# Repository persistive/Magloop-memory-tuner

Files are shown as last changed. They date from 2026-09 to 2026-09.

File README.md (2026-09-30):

# Magloop-memory-tuner
Using a CYD to steer a servo for the magloop variable condensator.
A tuning device with memory option for operating a magloop air capacitor The sketch is available in dutch and english language, functionality is the same. Base is a CYD unit for which a suitable casing is developed. Connections are part of the description in the .ino files

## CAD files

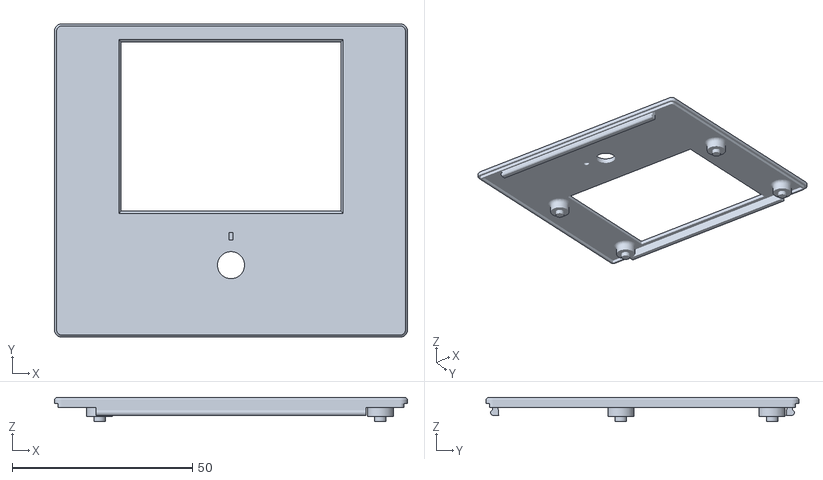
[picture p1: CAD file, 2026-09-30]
case front.stl
98.0 x 87.0 x 6.80

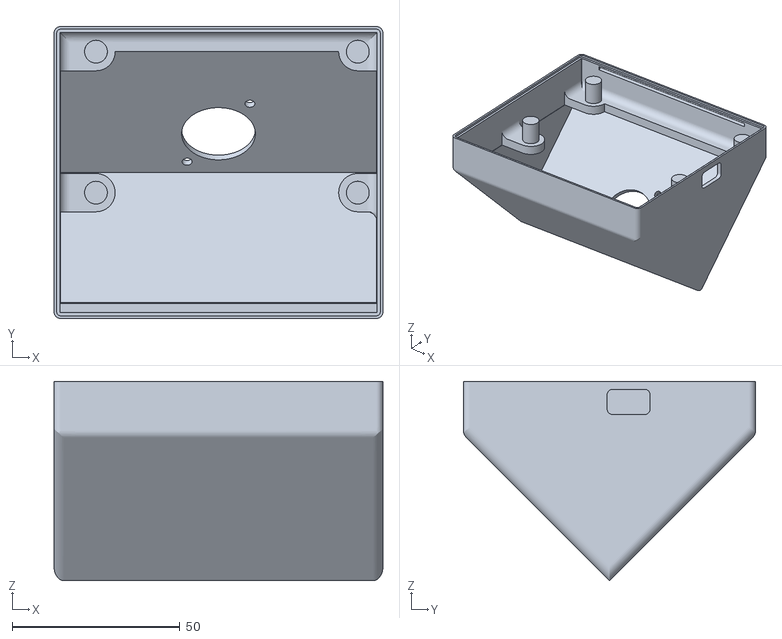
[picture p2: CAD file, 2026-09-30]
case rear.stl
98.0 x 87.0 x 59.4

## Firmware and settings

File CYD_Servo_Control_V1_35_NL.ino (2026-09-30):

/*
  =====================================================================
  CYD Servo/Frequentie Tuner
  =====================================================================
  Platform:
    - Cheap Yellow Display (CYD, board ESP32-2432S028R) met ESP-WROOM-32
    - TFT display ILI9341, 2.8", 240x320, resistief touch XPT2046
    - 8120MG digital servo met 270 graden slag, RECHTSTREEKS aangestuurd
      vanaf ESP32 GPIO27 via de ingebouwde LEDC-hardware-PWM (geen
      externe I2C-driver - servo zelf extern gevoed met 5V, GND
      gemeenschappelijk met de ESP32!). Via een 1:3 tandwielover-
      brenging levert de volledige 270 graden servoslag 0-100% op de
      uitgaande as (de condensator-vlinder) - alle posities in deze sketch
      ("Servo pos", MIN/MAX, mem pos-opslag, MAN-mode) zijn dan ook het
      UITGAANDE (vlinder-)percentage, 0-100%.
    - De kunstof tandriem zorgt tevens voor een goede isolatie tussen de hoge spanning
      van de condensator en de servo.
    - Zorg ervoor dat er geen speling aanwezig is op de vlinder as en tussen de tandwielen.
      Speling zal zorgen voor hysteresis en slechte repeatability.
    - Het instellen van de presets moet altijd van de laagste rotatie waarde naar de hoogste
      rotatie waarde geschieden i.v.m. hysteresis correctie. Indien later een preset wordt gekozen, 
      zal de servo eerst 4,4% onder de preset waarde aannemen om vervolgens naar 
      de preset waarde te gaan. Hiermee wordt de hysteresis voor een groot deel voorkomen.    
    - Servo-signaaldraad -> GPIO27 (SERVO_PIN)
      De meeste 5V-servo's accepteren een 3,3V-stuursignaal prima, maar controleer dit voor jouw servo.
    - Potentiometer (MAN-mode, tweede manier om de servo te bewegen):
      middenpin (wiper) -> GPIO35 (POT_PIN), buitenste pinnen -> 3V3 en GND.
      GPIO35 is een input-only ADC1-pin die op de meeste CYD-borden vrij
      beschikbaar is (vaak op de "P3"-header) - controleer dit voor jouw
      exemplaar en pas POT_PIN aan indien nodig.

  Benodigde libraries (Library Manager):
    - TFT_eSPI                    (Bodmer)
    - XPT2046_Touchscreen         (Paul Stoffregen)
    - Preferences                 (ingebouwd in ESP32 core)
  BELANGRIJK - ESP32-Arduino core versie (LEDC-API):
    Deze sketch gebruikt de LEDC-API van ESP32-Arduino core 3.x:
    ledcAttach(pin, freq, resolutie) / ledcWrite(pin, duty).

  BELANGRIJK - TFT_eSPI configuratie:
    In de library-map van TFT_eSPI moet het bestand User_Setup.h (of
    User_Setup_Select.h) zo ingesteld zijn dat onderstaande pinnen
    actief zijn (standaard CYD-bedrading):

      #define ILI9341_2_DRIVER
      #define TFT_WIDTH  240
      #define TFT_HEIGHT 320
      #define TFT_MISO 12
      #define TFT_MOSI 13
      #define TFT_SCLK 14
      #define TFT_CS   15
      #define TFT_DC    2
      #define TFT_RST  -1
      #define TFT_BL   21
      #define TFT_BACKLIGHT_ON HIGH
      #define SPI_FREQUENCY  40000000

  Opstarten:
    - De laatste servostand (sleutel "lastpos") en de laatste snelheidsinstelling
      (sleutel "speed") worden in NVS bewaard, pas 2 s nadat ze niet meer veranderen,
      en bij het opstarten teruggezet i.p.v. de standaard 50%.
      Bij een leeg geheugen (eerste keer) start alles op 50%.
    - Snelheidsslider is niet-lineair: de eerste helft van de slider dekt 1-25%
      (fijne, trage regeling), de tweede helft 25-100%.

  Werking (samengevat):
    - "mem pos" (1-180) is een presetadres in NVS - het is NIET
      gelijk aan het servopercentage. Onder dat adres worden twee waarden
      bewaard: de Freq-waarde en de actuele servostand/vlinder (Cap positie, in %) op
      het moment van opslaan.
    - Scherm 2: zet de servo/vlinder handmatig (via scherm 1) in de gewenste
      fysieke stand, ga naar scherm 2, kies een vrij "mem pos" nummer (of overschrijf een bestaande positie), 
      vul de bijbehorende "Freq" in en druk op "set". Freq en de op dat
      moment actuele Servo/vlinder positie worden samen opgeslagen onder dat
      mem pos adres.
    - Scherm 1: via "Freq (Khz)" en "set" wordt de volledige tabel
      doorzocht op de (dichtstbijzijnde) opgeslagen Freq, en de servo
      beweegt naar het daarbij opgeslagen servo/vlinder percentage (niet naar het
      mem pos-getal zelf).
    - Knop "MAN" (tussen MIN en MAX): schakelt de potentiometer als
      besturing in/uit. Bij het inschakelen wordt de actuele servostand
      vastgelegd als referentiepunt (dus geen sprong) zolang de potentiometer in het midden staat. 
      Zolang MAN actief is (rood), bepaalt de stand van de potentiometer rechtstreeks het
      servo/vlinder percentage (proportionele besturing, geen snelheidsbesturing) t.o.v.
      dat referentiepunt: pot in het midden = servo op de referentiestand,
      pot naar rechts (CW) = servo/vlinder verder rechtsom, pot naar links (CCW) =
      servo/vlinder verder linksom - en de servo blijft daar staan zodra de potmeter
      niet meer verder wordt gedraaid. Hoe ver de servo/vlinder vanaf de
      referentiestand kan komen bij volledige uitslag van de pot, wordt
      bepaald door de snelheids-slider (bij 100% tot 50% naar elke
      kant, bij een lagere instelling proportioneel minder). Rond het midden zit een dode
      zone zodat de servo niet "zoekt" als de pot niet perfect gecentreerd
      staat.
  =====================================================================
*/

#include <SPI.h>
#include <TFT_eSPI.h>
#include <XPT2046_Touchscreen.h>
#include <Preferences.h>

// --------------------------------------------------------------------
// Pin definities
// --------------------------------------------------------------------
#define XPT2046_IRQ  36
#define XPT2046_MOSI 32
#define XPT2046_MISO 39
#define XPT2046_CLK  25
#define XPT2046_CS   33

// Servo - rechtstreeks op een ESP32 GPIO via de LEDC-hardware-PWM
#define SERVO_PIN 22   // Servo 5V + GND EXTERN gevoed, GND gemeenschappelijk met ESP32!

// Ruwe touch-kalibratiewaarden - pas eventueel aan voor jouw exemplaar
#define TS_MINX 200
#define TS_MAXX 3900
#define TS_MINY 200
#define TS_MAXY 3900

// Potentiometer voor MAN-mode (tweede manier om de servo te bewegen)
#define POT_PIN            35    // ADC1_CH7, input-only - controleer/pas aan voor jouw CYD-exemplaar
#define POT_DEADBAND        0.06f // dode zone rond het midden (fractie van de volledige slag) - voorkomt
                                   // dat de servo rond het midden blijft "zoeken" door kleine ruis

// --------------------------------------------------------------------
// Objecten
// --------------------------------------------------------------------
SPIClass touchSPI = SPIClass(VSPI);
XPT2046_Touchscreen ts(XPT2046_CS, XPT2046_IRQ);
TFT_eSPI tft = TFT_eSPI();
Preferences prefs;

// --------------------------------------------------------------------
// Status / variabelen
// --------------------------------------------------------------------
enum Screen { SCREEN_P1, SCREEN_P2 };
Screen currentScreen = SCREEN_P1;

int servoPos      = 500;    // actuele servostand (vlinder) in STAPPEN VAN 0,1 PROCENT (0-1000 = 0-100%; 500 = 50,0% = midden)
int lastFoundMemPos = -1;   // mem pos die hoorde bij de laatst gevonden Freq-match (-1 = nog geen match)
int memPosValue   = 0;      // P2: "mem pos" (1-180) - 0 = nog leeg (start leeg, net als na het opslaan)
int freqValueP2   = 0;      // P2: "Freq" (10000-30000) -> wordt opgeslagen - 0 = nog leeg
int freqValueP1   = 10000;  // P1: "Freq (Khz)" (10000-30000) -> opzoeken
float speedPercent = 50.0f; // P1: "snelheid" (1-100%, in stappen van 0,1%)

int lastKnobX = -1;         // voor het wissen van de oude slider-indicatie

bool prevTouched = false;
bool manMode = false;       // P1: MAN-knop actief -> potentiometer bestuurt de servo
int manRefStep = 500;       // servostand (in stappen) die als "midden" geldt voor de pot -
                             // wordt bij het INSCHAKELEN van MAN gelijk gezet aan de actuele
                             // servoPos, zodat de pot een OFFSET is t.o.v. de stand van dat moment

// --------------------------------------------------------------------
// UI helper structuur
// --------------------------------------------------------------------
struct Btn {
  int x, y, w, h;
  const char* label;
};

bool hit(Btn b, int tx, int ty) {
  return (tx >= b.x && tx <= b.x + b.w && ty >= b.y && ty <= b.y + b.h);
}

void drawButton(Btn b, uint16_t fillColor, uint16_t txtColor = TFT_WHITE, int textSize = 2) {
  tft.fillRoundRect(b.x, b.y, b.w, b.h, 6, fillColor);
  tft.drawRoundRect(b.x, b.y, b.w, b.h, 6, TFT_WHITE);
  tft.setTextColor(txtColor, fillColor);
  tft.setTextSize(textSize);
  tft.setTextDatum(MC_DATUM);
  tft.drawString(b.label, b.x + b.w / 2, b.y + b.h / 2);
  tft.setTextDatum(TL_DATUM);
}

// --------------------------------------------------------------------
// Touch inlezen
// --------------------------------------------------------------------
bool getTouchPoint(int &x, int &y) {
  if (!ts.touched()) return false;
  TS_Point p = ts.getPoint();
  x = map(p.x, TS_MINX, TS_MAXX, 0, tft.width());
  y = map(p.y, TS_MINY, TS_MAXY, 0, tft.height());
  x = constrain(x, 0, tft.width() - 1);
  y = constrain(y, 0, tft.height() - 1);
  return true;
}

// Voorwaartse declaratie (functie zelf staat verderop, bij scherm 2)
bool memPosInUse(int memPos, int &outFreq, int &outPercentStep);

// ======================================================================
// NUMERIEK TOETSENBORD (modaal invoerscherm)
// ======================================================================
Btn kp_digits[12] = {
  {47,  45, 70, 35, "1"}, {125, 45, 70, 35, "2"}, {203, 45, 70, 35, "3"},
  {47,  88, 70, 35, "4"}, {125, 88, 70, 35, "5"}, {203, 88, 70, 35, "6"},
  {47, 131, 70, 35, "7"}, {125,131, 70, 35, "8"}, {203,131, 70, 35, "9"},
  {47, 174, 70, 35, "C"}, {125,174, 70, 35, "0"}, {203,174, 70, 35, "<-"}
};
Btn kp_cancel = {47, 214, 110, 24, "Annuleer"};
Btn kp_enter  = {163,214, 110, 24, "OK"};

void drawKeypadEntry(String entry) {
  tft.fillRect(20, 5, 280, 34, TFT_NAVY);
  tft.drawRect(20, 5, 280, 34, TFT_WHITE);
  tft.setTextColor(TFT_YELLOW, TFT_NAVY);
  tft.setTextSize(3);
  tft.setTextDatum(MR_DATUM);
  tft.drawString(entry, 292, 22);
  tft.setTextDatum(TL_DATUM);
}

void drawKeypadBase(const char* title) {
  tft.fillScreen(TFT_BLACK);
  tft.setTextColor(TFT_WHITE, TFT_BLACK);
  tft.setTextSize(1);
  tft.setTextDatum(TL_DATUM);
  tft.drawString(title, 20, 2);

  for (int i = 0; i < 12; i++) {
    drawButton(kp_digits[i], TFT_DARKGREY, TFT_WHITE, 2);
  }
  drawButton(kp_cancel, TFT_RED, TFT_WHITE, 2);
  drawButton(kp_enter,  TFT_DARKGREEN, TFT_WHITE, 2);
}

void drawKeypadError() {
  tft.fillRect(20, 5, 280, 34, TFT_RED);
  tft.drawRect(20, 5, 280, 34, TFT_WHITE);
  tft.setTextColor(TFT_WHITE, TFT_RED);
  tft.setTextSize(2);
  tft.setTextDatum(MC_DATUM);
  tft.drawString("Ongeldige waarde!", 160, 22);
  tft.setTextDatum(TL_DATUM);
}

// Blokkerend modaal toetsenbord. Geeft de ingevoerde (gevalideerde) waarde terug,
// of de oorspronkelijke waarde 'initVal' als er geannuleerd wordt.
long numericKeypad(const char* title, long minVal, long maxVal, long initVal) {
  String entry = ""; // altijd leeg starten, ongeacht de huidige waarde van het veld
  bool done = false;
  long result = initVal;

  drawKeypadBase(title);
  drawKeypadEntry(entry);

  // De aanraking die het veld opende, kan nog vastzitten op het scherm
  // (vinger nog niet losgelaten) precies op de plek waar toevallig een
  // cijfertoets van dit toetsenbord staat getekend. Start wasTouched daarom
  // op de HUIDIGE aanraakstatus i.p.v. altijd 'false', zodat die ene lopende
  // aanraking niet meteen als druk op die toets wordt gezien - pas een
  // nieuwe aanraking (na loslaten) telt als toetsdruk.
  int txInit, tyInit;
  bool wasTouched = getTouchPoint(txInit, tyInit);
  while (!done) {
    int tx, ty;
    bool touched = getTouchPoint(tx, ty);
    bool edge = touched && !wasTouched;

    if (edge) {
      bool handled = false;
      for (int i = 0; i < 12 && !handled; i++) {
        if (hit(kp_digits[i], tx, ty)) {
          String lbl = kp_digits[i].label;
          if (lbl == "C") {
            entry = "";
          } else if (lbl == "<-") {
            if (entry.length() > 0) entry.remove(entry.length() - 1);
          } else {
            if (entry.length() < 6) entry += lbl;
          }
          drawKeypadEntry(entry);
          handled = true;
        }
      }
      if (!handled && hit(kp_cancel, tx, ty)) {
        result = initVal;
        done = true;
      }
      if (!handled && hit(kp_enter, tx, ty)) {
        long v = entry.toInt();
        if (entry.length() > 0 && v >= minVal && v <= maxVal) {
          result = v;
          done = true;
        } else {
          drawKeypadError();
          delay(700);
          drawKeypadEntry(entry);
        }
      }
    }
    wasTouched = touched;
    delay(15);
  }
  return result;
}

// ======================================================================
// LIJST MET OPGESLAGEN FREQ-WAARDEN (modaal keuzescherm)
// ======================================================================
struct FreqEntry { int memPos; int freq; int percentStep; };
FreqEntry freqListEntries[180];
int freqListCount = 0;
int freqListPage = 0;
char freqListRowText[12][16];
Btn freqListRowBtn[12];
Btn freqListBtnPrev  = {10,  205, 90, 30, "Vorige"};
Btn freqListBtnNext  = {115, 205, 90, 30, "Volgende"};
Btn freqListBtnClose = {220, 205, 90, 30, "Sluiten"};

void drawFreqListPage(long currentFreq, int totalPages) {
  const int rowsPerPage = 12;
  const int rowsPerCol = 6;
  const int colW = 150, rowH = 26;
  tft.fillScreen(TFT_BLACK);
  tft.setTextColor(TFT_WHITE, TFT_BLACK);
  tft.setTextSize(2);
  tft.setTextDatum(TC_DATUM);
  char hdr[24];
  snprintf(hdr, sizeof(hdr), "Kies Freq (%d/%d)", freqListPage + 1, totalPages);
  tft.drawString(hdr, 160, 2);
  tft.setTextDatum(TL_DATUM);

  int startIdx = freqListPage * rowsPerPage;
  for (int i = 0; i < rowsPerPage; i++) {
    int idx = startIdx + i;
    int col = i / rowsPerCol;      // 0 = links, 1 = rechts
    int row = i % rowsPerCol;
    freqListRowBtn[i].x = 7 + col * (colW + 6);
    freqListRowBtn[i].y = 28 + row * 30;
    freqListRowBtn[i].w = colW;
    freqListRowBtn[i].h = rowH;
    freqListRowBtn[i].label = "";
    if (idx < freqListCount) {
      snprintf(freqListRowText[i], sizeof(freqListRowText[i]), "%d: %d",
               freqListEntries[idx].memPos, freqListEntries[idx].freq);
      freqListRowBtn[i].label = freqListRowText[i];
      bool highlight = (freqListEntries[idx].freq == currentFreq);
      drawButton(freqListRowBtn[i], highlight ? TFT_DARKGREEN : TFT_NAVY, TFT_WHITE, 2);
    }
  }
  drawButton(freqListBtnPrev,  (freqListPage > 0)              ? TFT_BLUE : TFT_DARKGREY, TFT_WHITE, 1);
  drawButton(freqListBtnNext,  (freqListPage < totalPages - 1)  ? TFT_BLUE : TFT_DARKGREY, TFT_WHITE, 1);
  drawButton(freqListBtnClose, TFT_RED, TFT_WHITE, 1);
}

// Blokkerend keuzescherm met alle opgeslagen Freq-waarden (gesorteerd op mem pos).
// Geeft de gekozen Freq terug, of 'currentFreq' als er geannuleerd wordt / niets is opgeslagen.
long chooseStoredFreq(long currentFreq) {
  freqListCount = 0;
  for (int p = 1; p <= 180; p++) {
    int freq, percentStep;
    if (memPosInUse(p, freq, percentStep)) {
      freqListEntries[freqListCount].memPos = p;
      freqListEntries[freqListCount].freq = freq;
      freqListEntries[freqListCount].percentStep = percentStep;
      freqListCount++;
    }
  }

  if (freqListCount == 0) {
    tft.fillScreen(TFT_BLACK);
    tft.setTextColor(TFT_WHITE, TFT_BLACK);
    tft.setTextSize(2);
    tft.setTextDatum(MC_DATUM);
    tft.drawString("Geen opgeslagen", 160, 100);
    tft.drawString("Freq-waarden", 160, 130);
    tft.setTextDatum(TL_DATUM);
    delay(1200);
    return currentFreq;
  }

  const int rowsPerPage = 12;
  int totalPages = (freqListCount + rowsPerPage - 1) / rowsPerPage;
  freqListPage = 0;
  long result = currentFreq;
  bool done = false;

  drawFreqListPage(currentFreq, totalPages);

  // Zelfde reden als bij numericKeypad(): de aanraking die "Lijst" opende kan
  // toevallig samenvallen met een rij/knop van dit keuzescherm. Start
  // wasTouched op de HUIDIGE aanraakstatus, niet op 'false'.
  int txInit, tyInit;
  bool wasTouched = getTouchPoint(txInit, tyInit);
  while (!done) {
    int tx, ty;
    bool touched = getTouchPoint(tx, ty);
    bool edge = touched && !wasTouched;

    if (edge) {
      if (hit(freqListBtnClose, tx, ty)) {
        done = true;
      } else if (hit(freqListBtnPrev, tx, ty) && freqListPage > 0) {
        freqListPage--;
        drawFreqListPage(currentFreq, totalPages);
      } else if (hit(freqListBtnNext, tx, ty) && freqListPage < totalPages - 1) {
        freqListPage++;
        drawFreqListPage(currentFreq, totalPages);
      } else {
        int startIdx = freqListPage * rowsPerPage;
        for (int i = 0; i < rowsPerPage; i++) {
          int idx = startIdx + i;
          if (idx < freqListCount && hit(freqListRowBtn[i], tx, ty)) {
            result = freqListEntries[idx].freq;
            done = true;
            break;
          }
        }
      }
    }
    wasTouched = touched;
    delay(15);
  }
  return result;
}

// ======================================================================
// NIET VLUCHTIG GEHEUGEN (Preferences / NVS)
// ======================================================================
// mem pos is een los presetadres (1-180), NIET gelijk aan het servopercentage.
// Onder dat adres worden TWEE waarden bewaard: de Freq en het actuele servo-
// percentage dat op het moment van opslaan werd weergegeven in "Servo pos".
void saveFreqAtMemPos(int memPos, int freq, int actualPercentStep) {
  char keyF[10], keyA[10];
  snprintf(keyF, sizeof(keyF), "p%df", memPos);
  snprintf(keyA, sizeof(keyA), "p%da", memPos);
  prefs.putInt(keyF, freq);
  prefs.putInt(keyA, actualPercentStep);
  Serial.printf("[opslaan] mem pos %d -> Freq %d, %.1f%%\n", memPos, freq, actualPercentStep / 10.0f);
}

// Zoekt in alle opgeslagen presets naar de Freq die het best overeenkomt met 'freq'
// en geeft het DAARBIJ OPGESLAGEN SERVOPERCENTAGE terug (niet het mem pos-getal zelf).
// Geeft -1 terug als er nog niets is opgeslagen.
int findPercentForFreq(int freq, int &foundMemPos) {
  int bestPercentStep = -1;
  int bestMemPos = -1;
  long bestDiff = 2147483647;

  Serial.printf("[zoeken] gevraagde Freq = %d\n", freq);
  for (int p = 1; p <= 180; p++) {
    char keyF[10], keyA[10];
    snprintf(keyF, sizeof(keyF), "p%df", p);
    snprintf(keyA, sizeof(keyA), "p%da", p);
    if (prefs.isKey(keyF) && prefs.isKey(keyA)) {
      int storedFreq        = prefs.getInt(keyF, -1);
      int storedPercentStep = prefs.getInt(keyA, -1);
      Serial.printf("  mem pos %d -> Freq %d, %.1f%%\n", p, storedFreq, storedPercentStep / 10.0f);
      if (storedFreq == freq) {
        Serial.printf("  -> exacte match: mem pos %d, %.1f%%\n", p, storedPercentStep / 10.0f);
        foundMemPos = p;
        return storedPercentStep; // exacte match
      }
      long diff = abs((long)storedFreq - (long)freq);
      if (diff < bestDiff) {
        bestDiff = diff;
        bestPercentStep = storedPercentStep;
        bestMemPos = p;
      }
    }
  }
  Serial.printf("[zoeken] beste (niet-exacte) match: mem pos %d, %.1f%%\n", bestMemPos, bestPercentStep / 10.0f);
  foundMemPos = bestMemPos;
  return bestPercentStep;
}

// ======================================================================
// SERVO BESTURING
// ======================================================================
// De servo wordt aangestuurd via microseconden i.p.v. hele procenten, zodat
// een resolutie van 0,1% per stap mogelijk is.
//
// Deze servo heeft een fysieke slag van 270 graden (pulsbreedte 500-2500 us
// over het VOLLEDIGE bereik). Via een 1:3 tandriem overbrenging levert dat
// 0-100% op de uitgaande as (de condensator-vlinder): de servo draait dus
// 3x zo ver als de vlinder. Omdat de volledige 270 graden servoslag exact
// overeenkomt met de volledige 500-2500 us pulsbreedte, is de puls nog
// steeds recht evenredig met het UITGAANDE (vlinder-)percentage. Het bereik
// is verdeeld in 1000 stappen van 0,1% (0-100%): stap 0 = 0,0% (vlinder),
// stap 1000 = 100,0% (vlinder). Omdat de volledige pulsbreedte (2000 us)
// over die 1000 stappen wordt verdeeld, komt elke stap overeen met exact
// 2000 / 1000 = 2 us pulsbreedteverschil - de servo wordt dus per 2 us
// aangestuurd.
//
// LET OP - haalbare resolutie via de ESP32 LEDC-hardware-PWM:
// LEDC verdeelt de PWM-periode (bij 50 Hz dus 20000 us) in 2^LEDC_RESOLUTION_BITS
// telstappen. Met LEDC_RESOLUTION_BITS=16 is dat 65536 stappen over 20000 us,
// dus ca. 0,31 us per telstap - ruim fijner dan de 2000/1000 = 2 us die je
// nodig hebt voor een echte 0,1%-stap. Elke software-stap geeft hier dus
// ook daadwerkelijk een andere fysieke pulsbreedte.
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
void loop() {
  int tx, ty;
  bool touched = getTouchPoint(tx, ty);

  if (currentScreen == SCREEN_P1) {
    handleScreenP1(touched, tx, ty, prevTouched);
  } else {
    handleScreenP2(touched, tx, ty, prevTouched);
  }

  prevTouched = touched;

  saveServoPosIfSettled();   // laatste servostand bewaren zodra de servo stilstaat

  // Alleen een vaste rustpauze als er niets wordt aangeraakt/bewogen -
  // tijdens actieve servobeweging bepaalt uitsluitend de snelheidsinstelling het tempo.
  if (!touched) {
    delay(15);
  }
}

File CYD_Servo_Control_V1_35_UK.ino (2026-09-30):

/*
  =====================================================================
  CYD Servo/Frequentie Tuner
  =====================================================================
  Copyright (c) 2026 [HF-Tech]
  Permission is hereby granted to any person obtaining a copy of this software and associated 
  documentation files to view, download, and use the software for personal, non-commercial educational purposes only.
  THE SOFTWARE IS PROVIDED "AS IS", WITHOUT WARRANTY OF ANY KIND.
  STRICT RESTRICTIONS:
    You may NOT sell, rent, lease, or license this software.
    You may NOT use this software for any commercial purposes or financial gain.
    You may NOT distribute or redistribute this software for commercial purposes.
  
  Platform:
    - Cheap Yellow Display (CYD, board ESP32-2432S028R) with ESP-WROOM-32
    - TFT display ILI9341, 2.8", 240x320, resistief touch XPT2046
    - 8120MG digital servo with 270-degree rotation, controlled directly
      from ESP32 GPIO27 via the built-in LEDC hardware PWM. Via a 1:3 gear ratio, the full
      270-degree servo travel translates to a 0–100% range on the
      output shaft (the capacitor butterfly valve); consequently, all
      positions in this sketch ("Servo pos", MIN/MAX, stored positions, MAN mode) 
      refer to the OUTPUT (butterfly) percentage, 0–100%.
    - The synthetic toothed belt also ensures good insulation between the high voltage of the 
      capacitor and the servo.
    - Ensure there is no backlash in the butterfly valve shaft or between the gears.
      Backlash will cause hysteresis and poor repeatability.
    - Presets must always be set from the lowest rotation value to the highest to account 
      for hysteresis correction. If a preset is selected later, the servo will first move to 
      a position 4.4% below the preset value before moving to the preset value itself. 
      This largely eliminates hysteresis.    
    - Servo signal wire -> GPIO27 (SERVO_PIN)
      Most 5V servos accept a 3.3V control signal without issue, but check this for your specific servo.
    - Potentiometer (MAN mode, second method to move the servo):
      middle pin (wiper) -> GPIO35 (POT_PIN), outer pins -> 3V3 and GND.
      GPIO35 is an input-only ADC1 pin that is freely available on most CYD boards
      (often on the "P3" header) – check this for your specific
      unit and adjust POT_PIN if necessary.

  Needed libraries (Library Manager):
    - TFT_eSPI                    (Bodmer)
    - XPT2046_Touchscreen         (Paul Stoffregen)
    - Preferences                 (ingebouwd in ESP32 core)
  Important - ESP32-Arduino core versie (LEDC-API):
    This sketch uses the LEDC-API of ESP32-Arduino core 3.x:
    ledcAttach(pin, freq, resolutie) / ledcWrite(pin, duty).

  Important - TFT_eSPI configuration:
    In the TFT_eSPI library folder, the User_Setup.h (or
    User_Setup_Select.h) file must be configured so that the following pins
    are active (standard CYD wiring):

      #define ILI9341_2_DRIVER
      #define TFT_WIDTH  240
      #define TFT_HEIGHT 320
      #define TFT_MISO 12
      #define TFT_MOSI 13
      #define TFT_SCLK 14
      #define TFT_CS   15
      #define TFT_DC    2
      #define TFT_RST  -1
      #define TFT_BL   21
      #define TFT_BACKLIGHT_ON HIGH
      #define SPI_FREQUENCY  40000000

  Startup:
    - The last servo position (key "lastpos") and the last speed setting
      (key "speed") are saved to NVM (non volatile memory) 2 seconds after they stop changing—
      and restored upon startup instead of defaulting to 50%.
      If memory is empty (first run), everything starts at 50%.
    - The speed slider is non-linear: the first half of the slider covers 1–25%
      (fine, slow control), while the second half covers 25–100%.

  Operation (summary):
    - "mem pos" (1–180) is a preset address in NVM is NOT
      equivalent to the servo percentage. Two values are stored at this address:
      the Freq value and the current servo/cap position (Cap position, in %)
      at the time of saving.
    - Screen 2: manually set the servo/cap to the desired
      physical position (via screen 1), go to screen 2, select an available "mem pos" number
      (or overwrite an existing position), enter the corresponding "Freq",
      and press "set". The Freq and the current servo/cap position
      are saved together under that "mem pos" address.
    - Screen 1: using "Freq (kHz)" and "set", the entire table is
      searched for the (nearest) stored frequency, and the servo
      moves to the corresponding stored servo/cap percentage (not to the
      memory position value itself).
    - "MAN" button (between MIN and MAX): enables/disables the potentiometer as a
      control input. Upon activation, the current servo position is
      recorded as the reference point (ensuring no sudden jump), provided the potentiometer is centered.
      While MAN is active (indicated by a yellow button), the potentiometer position directly determines
      the servo/butterfly valve percentage (proportional control, not speed control) relative to
      that reference point: pot centered = servo at the reference position,
      pot turned right (CW) = servo/butterfly moves further clockwise, pot turned left (CCW) =
      servo/butterfly moves further counter-clockwise—and the servo holds its position once the
      potentiometer stops moving. The extent of the servo/butterfly movement from the
      reference position at full potentiometer deflection is
      determined by the speed slider. A dead zone around the center prevents the servo from 
      "hunting" if the potentiometer is not perfectly centered.
  =====================================================================
*/

#include <SPI.h>
#include <TFT_eSPI.h>
#include <XPT2046_Touchscreen.h>
#include <Preferences.h>

// --------------------------------------------------------------------
// Pin definitions
// --------------------------------------------------------------------
#define XPT2046_IRQ  36
#define XPT2046_MOSI 32
#define XPT2046_MISO 39
#define XPT2046_CLK  25
#define XPT2046_CS   33

// Servo - directly connected to an ESP32 GPIO via the LEDC hardware PWM
#define SERVO_PIN 22   // Servo 5V + GND powered externally; GND shared with ESP32!

// Raw touch calibration values – adjust for your specific unit if necessary
#define TS_MINX 200
#define TS_MAXX 3900
#define TS_MINY 200
#define TS_MAXY 3900

// Potentiometer for MAN mode (second way to move the servo)
#define POT_PIN            35    // ADC1_CH7, input-only - check/adjust for your specific CYD unit
#define POT_DEADBAND        0.06f // dead zone around the center (fraction of the full stroke) – prevents
                                   // that the servo keeps "hunting" around the center due to slight noise
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
